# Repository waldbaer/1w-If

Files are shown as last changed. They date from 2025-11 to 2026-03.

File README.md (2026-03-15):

# 1-Wire Interface Logo

An ESP32-based 1-Wire interface supporting access with physical ethernet and MQTT protocol.

**Overview**

Overview Diagram

**Hardware**

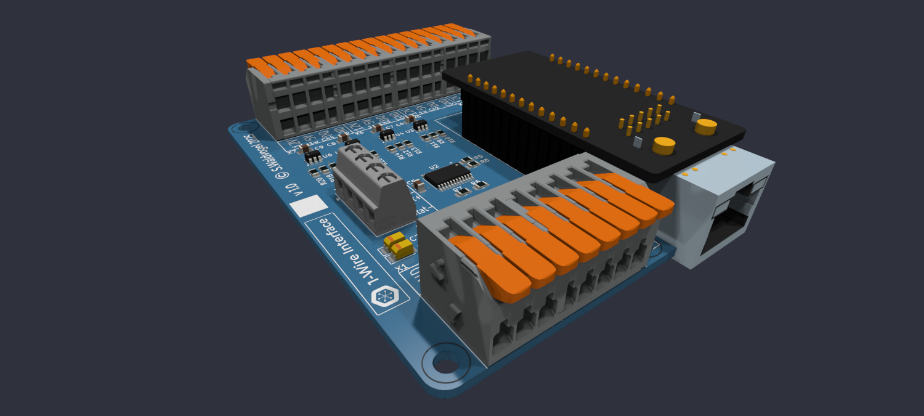
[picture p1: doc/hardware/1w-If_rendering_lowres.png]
PCB Rendering


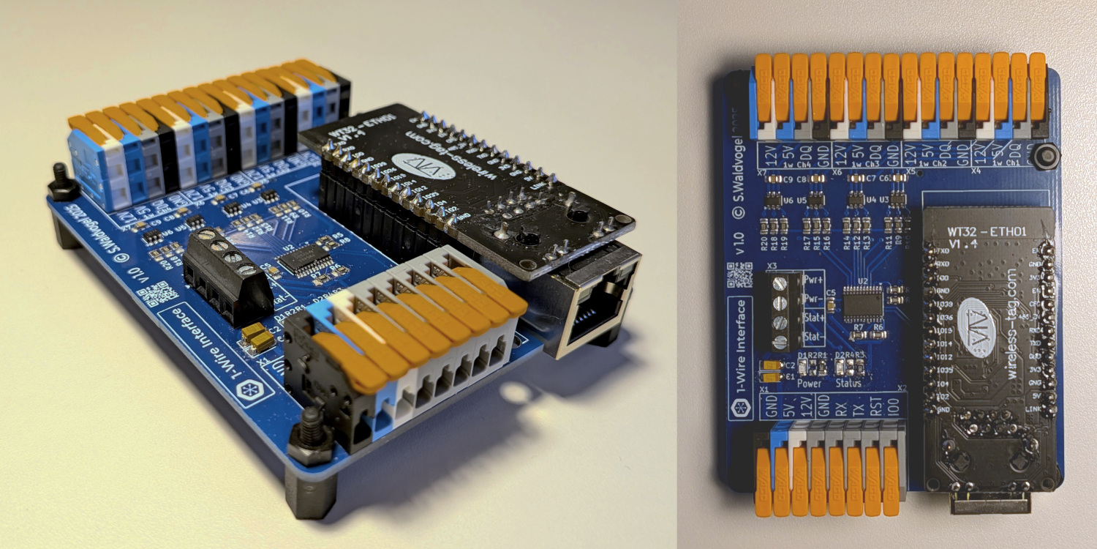
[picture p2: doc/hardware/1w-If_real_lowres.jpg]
PCB Real


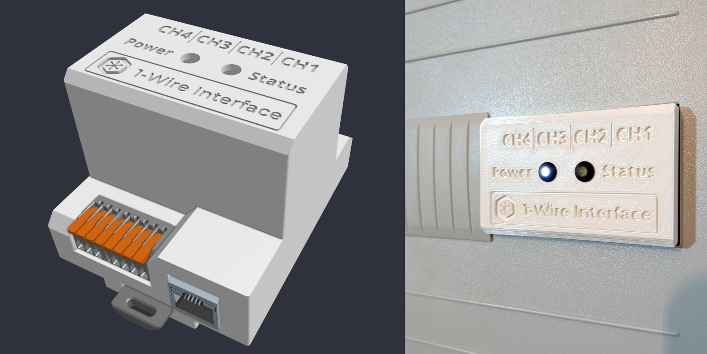
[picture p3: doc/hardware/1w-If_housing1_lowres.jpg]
Housing1


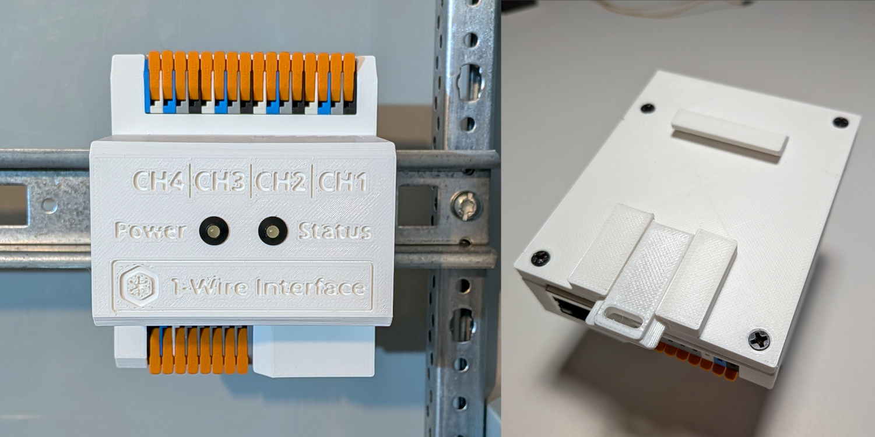
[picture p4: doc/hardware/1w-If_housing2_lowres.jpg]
Housing2


[Schematic](doc/hardware/1w-If_schematic.pdf)

## Key Features

* Access 1-wire devices via ethernet / MQTT protocol
* 4 independent 1-Wire channels with hardware bus masters
* Over-the-air (OTA) updates (web interface and espota protocol)
* Responsive web interface for configuration
  <br/>
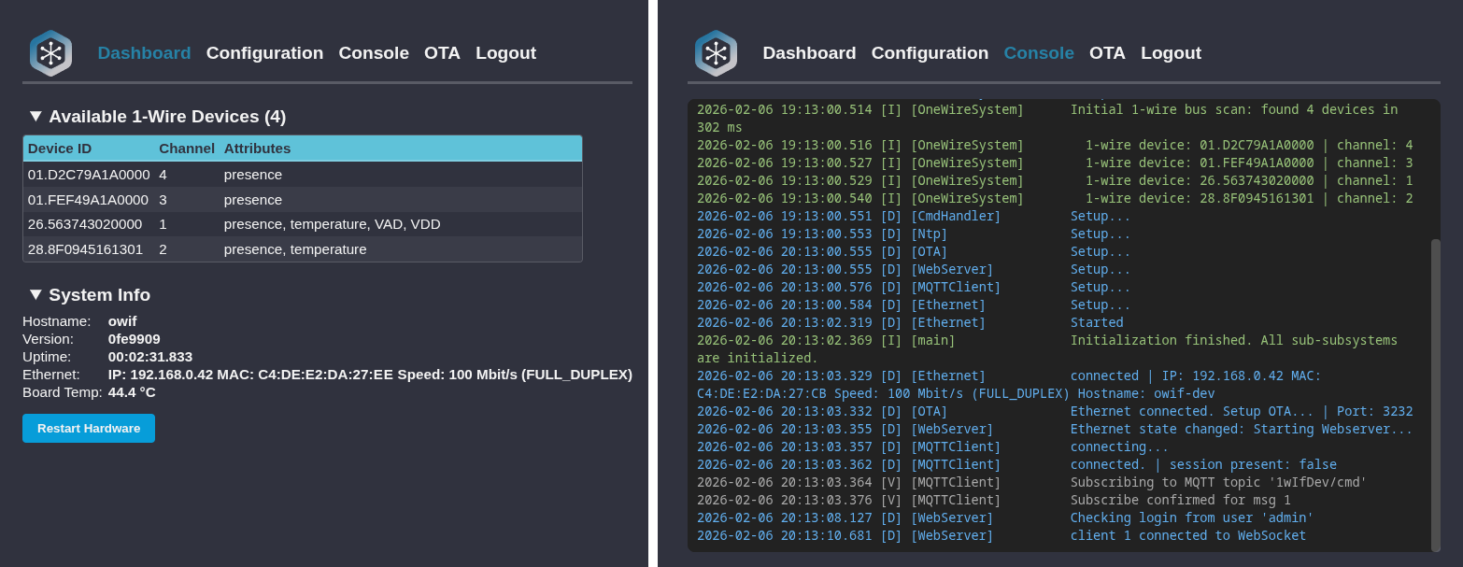
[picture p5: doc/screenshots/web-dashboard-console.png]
Screenshot Dashboard / Console
  
* NTP for clock synchronization
* 3D printed housing

## Supported 1-Wire devices

* DS2401 / DS2411 (Silicon Serial Number)
  * Unique Unique 64-Bit Serial Code

* DS18B20 (Temperature sensor)
  * Configurable resolution temperature

* DS2438  (Smart Battery Monitor)
  * Temperature, VAD, VDD

## Web-Interface

Default login:
- Username: `admin`
- Password: `1w-If`

## MQTT API
`%topic%` is a configurable prefix. Default: `1wIf`

### Commands

General MQTT topic for commands: `%topic%/cmd`

General MQTT topic for responses and status: `%topic%/stat`

Payload Format:

```
{
  "action": "<command>",
  ... action specific parameters / attributes ...
}
```

#### Command 'Restart'

Restart the entire system.
```
{
  "action": "restart",
}
```

Response:
```
{
  "action": "restart",
  "acknowledge": true,
  "time": "2026-02-03 20:20:07.955"
}
```

#### Command 'SysInfo'

Get system info.
```
{
  "action": "sysinfo",
}
```

Response:
```
{
  "action": "sysinfo",
  "state": "online",
  "version": "1.1.0",
  "uptime": "14d 12:07:12.834",
  "board_temp": 43.9,
  "ethernet": {
    "ip": "192.168.0.100",
    "mac": "89:30:5A:47:7D:0C",
    "link_speed": 100,
    "link_mode": "FULL_DUPLEX"
  },
  "time": "2026-03-15 17:02:09.720"
}
```

#### Command 'Scan'

Scan 1-wire buses for all available devices:

```
{
  "action": "scan",
}
```

Scan 1-wire buses for availability of a specific device:

```
{
  "action": "scan",
  "device_id": "01.D2C79A1A0000"
}
```

Scan 1-wire buses for availability of a specific device family:

```
{
  "action": "scan",
  "family_code": 40
}
```

The response lists all available devices and the supported attributes (for `Read` / `Subscribe` / `Unsubscribe` commands):

Example Response:
```
{
  "action": "scan",
  "devices": [
    {
      "channel": 1,
      "device_id": "01.D2C79A1A0000",
      "presence": true,
      "attributes": ["presence"]
    },
    {
      "channel": 1,
      "device_id": "28.8F0945161301",
      "presence": true,
      "attributes": ["presence", "temperature"]
    },
    {
      "channel": 2,
      "device_id": "26.563743020000",
      "presence": true,
      "attributes": ["presence", "temperature", "VAD", "VDD"]
    },
    ...
  ],
  "time": "2026-02-03 20:16:46.010"
}
```

#### Command 'Read'

Read value(s) of a single 1-wire device:

```
{
  "action": "read",
  "device_id": "28.8F0945161301",
  "attribute": "temperature"
}
```

Example Response:
```
{
  "action": "read",
  "device": {
    "channel": 1,
    "device_id": "28.8F0945161301",
    "temperature": 24.75
  },
  "time": "2025-02-03 19:10:07.955"
}
```

Read value(s) of a specific device family:

```
{
  "action": "read",
  "family_code": 40,
  "attribute": "temperature"
}
```

Example Response:
```
{
  "action": "read",
  "family_code": 40,
  "devices": [
    {
      "channel": 1,
      "device_id": "28.8F0945161301",
      "temperature": 24.75
    },
    ...
  ],
  "time": "2025-02-03 18:10:02.844"
}
```

Also the presence of a device can be accessed via the read command using the attribute `presence`.
This is similar to the scan command.

```
{
  "action": "read",
  "device_id": "28.8F0945161301",
  "attribute": "presence"
}
```

Example Response:
```
{
  "action": "read",
  "device": {
    "channel": 2,
    "device_id": "28.8F0945161301",
    "presence": true
  },
  "time": "2026-01-17 05:19:02.170"
}
```

#### Command 'Subscribe / Unsubscribe'

Subscribe to cyclic updates for 1-wire device attributes.
After successful subscription this triggers internally a `Read` command with the configured internal time.

Unit of 'interval': _milliseconds_

```
{
  "action": "subscribe",
  "device_id": "28.8F0945161301",
  "attribute": "temperature",
  "interval": 1000
}
```

Example response acknowledging the successful subscription:
```
{
  "action": "subscribe",
  "acknowledge": true,
  "device": {
    "device_id": "28.8F0945161301"
  },
  "time": "2025-08-05 13:10:22.970"
}
```

Unsubscribe from the attribute:
```
{
  "action": "unsubscribe",
  "device_id": "28.8F0945161301",
  "attribute": "temperature"
}
```

It is also possible to subscribe to the attribute `presence` to get cyclic updates about the availability of dedicated
devices:
```
{
    "action": "subscribe",
    "device_id": "01.D2C79A1A0000",
    "attribute": "presence",
    "interval": 2000
}
```

Example of the `Read` command for attribute `presence` cyclically triggered by the subscription:
```
{
  "action": "read",
  "device": {
     "channel": 3,
     "device_id": "01.D2C79A1A0000",
     "presence": false
  },
  "time": "2026-01-20 14:55:36.781"
}
```

### Last Will and Testament

The MQTT Last Will and Testament (LWT) message is published to the `%topic%/stat` topic.

The LWT contains the attribute `state` with the value `offline`.
It also includes the timestamp of when the LWT was registered with the MQTT broker.

Example:
```
{
  "state": "offline",
  "time": "2026-02-27 21:52:59.016"
}
```

During startup and registration with the MQTT broker, the same message is published with `state` set to `online`.
In this case, the timestamp contains the time of the initial MQTT subscription performed by the 1-Wire interface.

Example:
```
{
  "state": "online",
  "time": "2026-02-27 22:04:17.125"
}
```

## Development

### Firmware
```
cd firmware

# Build firmware
./build.sh

# Flash firmware + LittleFS filesystem
./flash.sh
./flash-fs.sh

# Optional: Monitor via websocket
./monitor.sh
```

Run tests
```
cd test
pdm install --dev

# Create a test_env_config.yaml in the test directory
cp example_test_env_config.yaml test_env_config.yaml
# Adapt all MQTT / device settings test_env_config.yaml
vim test_env_config.yaml

# Execute tests
pdm run tests
# Alternative: with filter
pdm run tests -k "<test name filter>"

# Lint/Format of test implementations
pdm run lint
pdm run format
```

### Hardware

- PCB designed with [KiCad](https://www.kicad.org/)
- Production files created with KiCad plugin [KiCAD JLCPCB tools](https://github.com/Bouni/kicad-jlcpcb-tools)
- Housing designed with [onshape.com](https://www.onshape.com/)

#### 3D Printing Settings

* Bottom / Top Parts:
  * Material: PLA / HPA
  * 0.4mm nozzle
  * Perimeters: 2
  * Infill:
    * General: 15%
    * Screw Domes: 100% concentric
* DIN Rail Clip:
  * Material: PETG
  * 0.4mm nozzle
  * Perimeters: 2
  * Infill:
    * General: 15%
    * Screw Domes: 100% concentric

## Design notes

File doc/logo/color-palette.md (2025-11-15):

# 1-Wire Interface - Color Palette

## Based on transparent logo
[Adobe Theme Extractor](https://color.adobe.com/de/create/image)

- <span style="color: #079DD9;">⬛</span> #079DD9
- <span style="color: #2682A6;">⬛</span> #2682A6
- <span style="color: #5FC2D9;">⬛</span> #5FC2D9
- <span style="color: #F2F2F2;">⬛</span> #F2F2F2
- <span style="color: #30323e;">⬛</span> #30323e

Extra colors:
- <span style="color: #3a3c48;">⬛</span> #3a3c48: Extra light difference to dark <span style="color: #30323e;">⬛</span> #30323e

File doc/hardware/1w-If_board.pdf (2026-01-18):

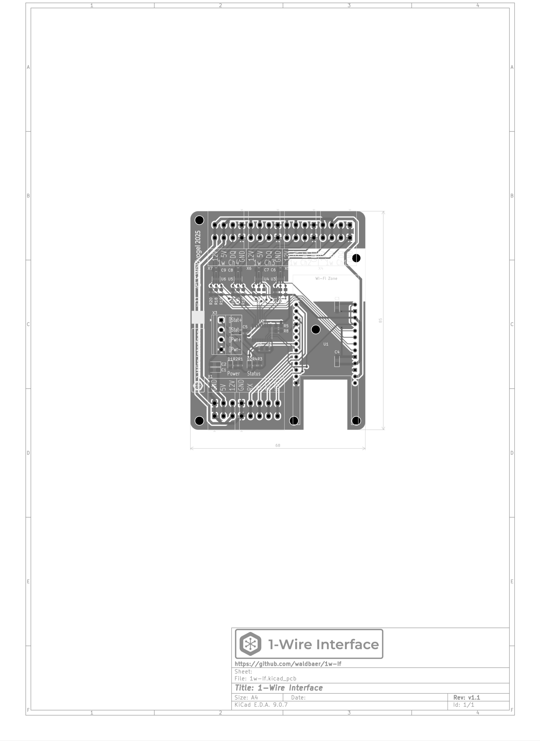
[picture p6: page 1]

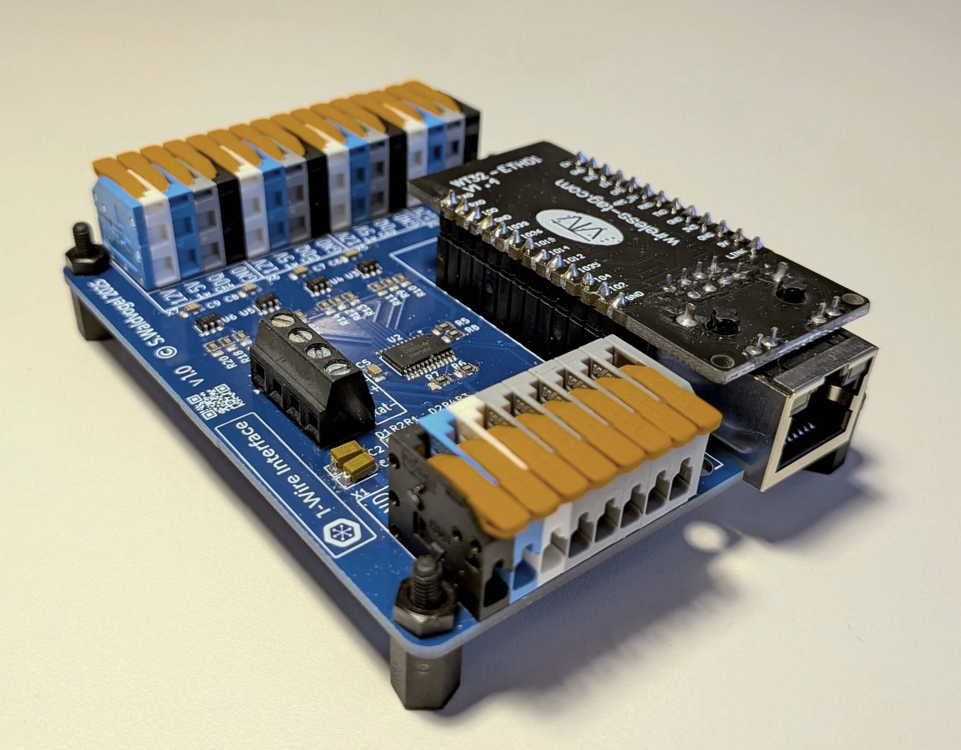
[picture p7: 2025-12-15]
doc/hardware/1w-If_real_side.jpg

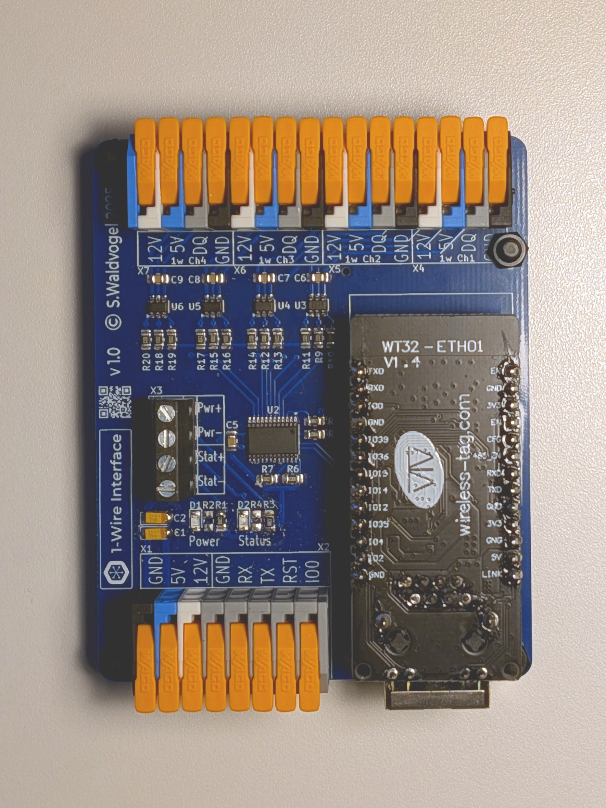
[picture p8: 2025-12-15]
doc/hardware/1w-If_real_top.jpg

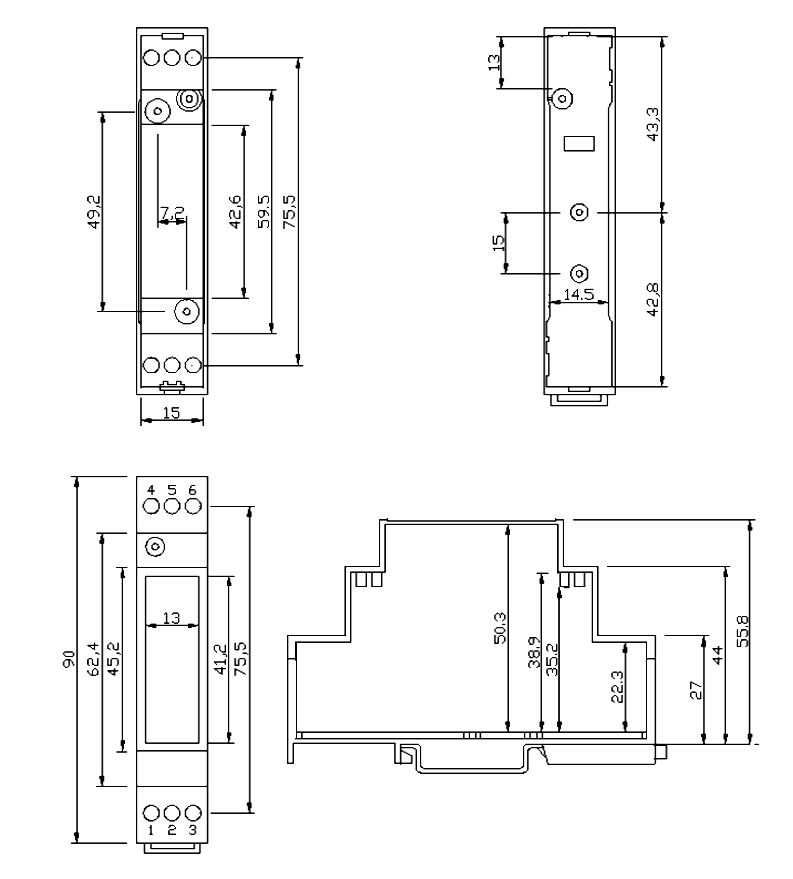
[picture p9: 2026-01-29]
doc/hardware/din-rail-dimensions.jpg

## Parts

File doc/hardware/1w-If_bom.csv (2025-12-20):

Reference | Value | Datasheet | Footprint | Qty | DNP
C1,C2,C3,C4 | 10uF | https://www.lcsc.com/product-detail/C7171.html?href=jlc-SMT%2F%3Fhref | Capacitor_Tantalum_SMD:CP_EIA-3216-18_Kemet-A_HandSolder | 4
C5,C6,C7,C8,C9 | 100nF | https://www.lcsc.com/product-detail/C49678.html?href=jlc-SMT%2F%3Fhref | Capacitor_SMD:C_0805_2012Metric_Pad1.18x1.45mm_HandSolder | 5
D1 | LED Power 5mA | https://www.lcsc.com/product-detail/C2297.html?href=jlc-SMT%2F%3Fhref | LED_SMD:LED_0805_2012Metric_Pad1.15x1.40mm_HandSolder | 1
D2 | LED Status 5mA | https://www.lcsc.com/product-detail/C2297.html?href=jlc-SMT%2F%3Fhref | LED_SMD:LED_0805_2012Metric_Pad1.15x1.40mm_HandSolder | 1
D3 | LED Power ext. 20mA | https://www.reichelt.de/de/de/shop/suche/3034W2D-EHD-A?GROUPINDEX=0&search=3034W2D-EHD-A | LED_SMD:LED_0805_2012Metric_Pad1.15x1.40mm_HandSolder | 1
D4 | LED Status ext. 20mA | https://www.reichelt.de/de/de/shop/suche/3034W2D-EHD-A?GROUPINDEX=0&search=3034W2D-EHD-A | LED_SMD:LED_0805_2012Metric_Pad1.15x1.40mm_HandSolder | 1
R1,R2,R3,R4 | 1k | https://www.lcsc.com/product-detail/C17408.html?href=jlc-SMT%2F%3Fhref | Resistor_SMD:R_0805_2012Metric_Pad1.20x1.40mm_HandSolder | 4
R5,R6,R7,R8,R9,R10,R12,R13,R15,R16,R18,R19 | 10k | https://www.lcsc.com/product-detail/C17414.html?href=jlc-SMT%2F%3Fhref | Resistor_SMD:R_0805_2012Metric_Pad1.20x1.40mm_HandSolder | 12
R11,R14,R17,R20 | 2.2k | https://www.lcsc.com/product-detail/C17520.html?href=jlc-SMT%2F%3Fhref | Resistor_SMD:R_0805_2012Metric_Pad1.20x1.40mm_HandSolder | 4
U1 | WT32-ETH01 | http://www.wireless-tag.com/wp-content/uploads/2020/08/WT32-ETH01%E8%A7%84%E6%A0%BC%E4%B9%A6V1.2EN%EF%BC%88%E8%8B%B1%E6%96%87%EF%BC%89.pdf | WT32-ETH01:WT32-ETH01_inv_mount | 1
U2 | TCA9548APWR | http://www.ti.com/lit/ds/symlink/tca9548a.pdf | Package_SO:TSSOP-24_4.4x7.8mm_P0.65mm | 1
U3,U4,U5,U6 | DS2484R | https://www.analog.com/DS2484/datasheet | Package_TO_SOT_SMD:SOT-23-6 | 4
X1 | PowerSupply | https://www.reichelt.de/de/de/shop/produkt/leiterplattenklemme_mit_hebel_1_5_mm_rm_3_5_mm_3-polig-372627 | TerminalBlock_WAGO_3D:TerminalBlock_WAGO_2601-1103_1x03_P3.50mm_Horizontal | 1
X2 | Debug Terminal | https://www.reichelt.de/de/de/shop/produkt/leiterplattenklemme_mit_hebel_1_5_mm_rm_3_5_mm_5-polig-387513 | TerminalBlock_WAGO_3D:TerminalBlock_WAGO_2601-1105_1x05_P3.50mm_Horizontal | 1
X3 | Ext LED Terminal | https://www.reichelt.de/de/de/shop/produkt/anschlussklemme_4-pol_1_5_mm_rm_3_81-72035 | TerminalBlock_MetzConnect_3D:TerminalBlock_MetzConnect_Type086_RT03404HBLC_1x04_P3.81mm_Horizontal | 1
X4 | 1-Wire Ch1 | https://www.reichelt.de/de/de/shop/produkt/leiterplattenklemme_mit_hebel_1_5_mm_rm_3_5_mm_4-polig-387512 | TerminalBlock_WAGO_3D:TerminalBlock_WAGO_2601-1104_1x04_P3.50mm_Horizontal | 1
X5 | 1-Wire Ch2 | https://www.reichelt.de/de/de/shop/produkt/leiterplattenklemme_mit_hebel_1_5_mm_rm_3_5_mm_4-polig-387512 | TerminalBlock_WAGO_3D:TerminalBlock_WAGO_2601-1104_1x04_P3.50mm_Horizontal | 1
X6 | 1-Wire Ch3 | https://www.reichelt.de/de/de/shop/produkt/leiterplattenklemme_mit_hebel_1_5_mm_rm_3_5_mm_4-polig-387512 | TerminalBlock_WAGO_3D:TerminalBlock_WAGO_2601-1104_1x04_P3.50mm_Horizontal | 1
X7 | 1-Wire Ch4 | https://www.reichelt.de/de/de/shop/produkt/leiterplattenklemme_mit_hebel_1_5_mm_rm_3_5_mm_4-polig-387512 | TerminalBlock_WAGO_3D:TerminalBlock_WAGO_2601-1104_1x04_P3.50mm_Horizontal | 1
X10,X11 | Conn_01x13_Socket | https://www.reichelt.de/de/de/shop/produkt/buchsenleiste_2_54mm_1x16_trennbar_verzinnt-283793 |  | 2

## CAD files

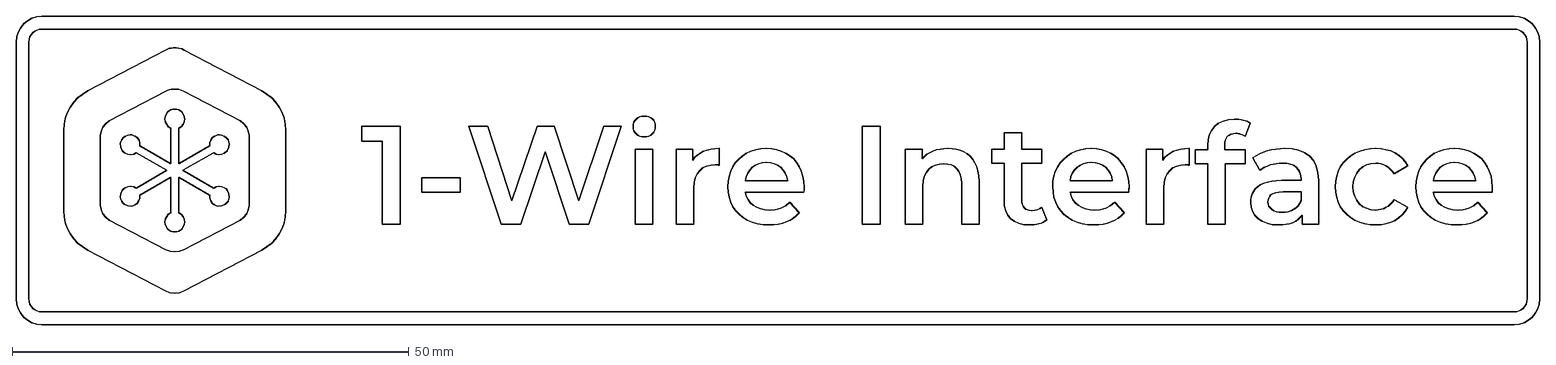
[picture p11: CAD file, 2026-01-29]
doc/logo/logo-white-transparent-framed.inkscape.dxf
192.1 x 38.9 mm

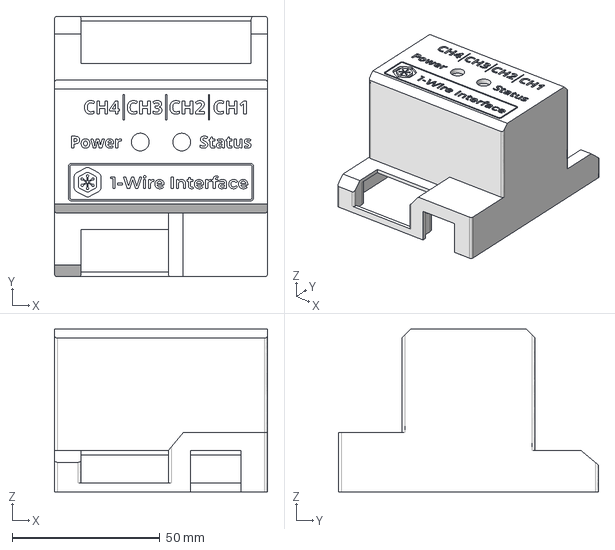
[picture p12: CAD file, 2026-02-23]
hardware/housing/1w-If Housing - Top.step
72.0 x 88.0 x 55.0 mm

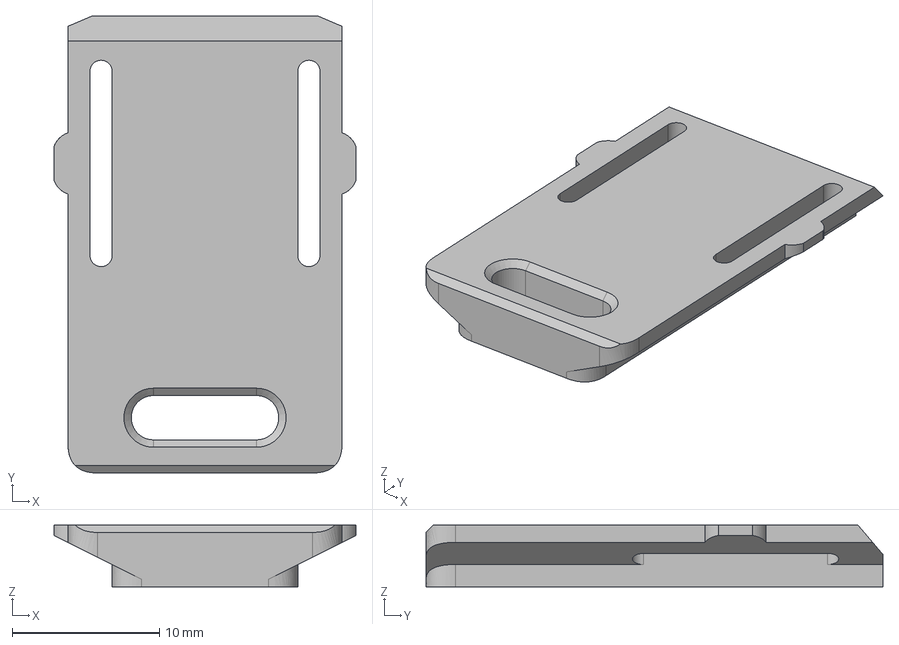
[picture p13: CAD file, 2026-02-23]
hardware/housing/1w-If Housing - DIN Rail Clip.step
20.5 x 31.0 x 4.20 mm

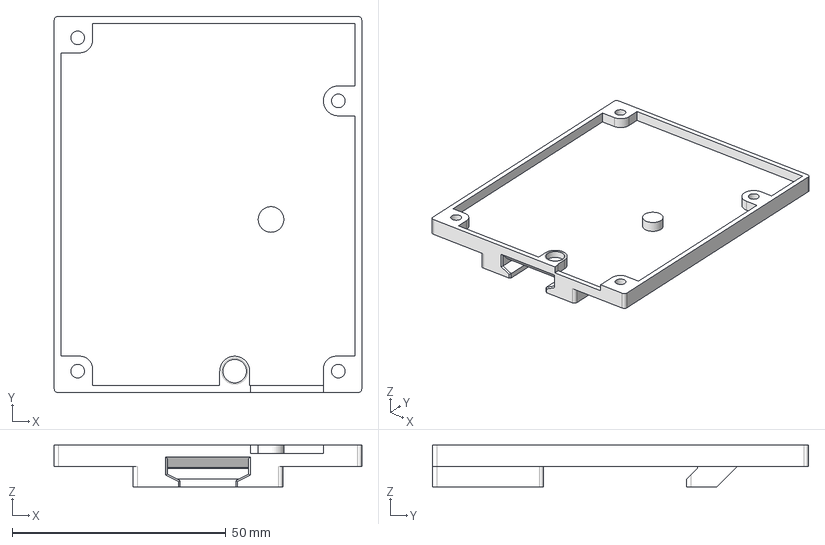
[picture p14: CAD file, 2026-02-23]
hardware/housing/1w-If Housing - Bottom.step
72.0 x 88.0 x 9.80 mm

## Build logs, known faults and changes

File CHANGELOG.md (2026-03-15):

# Changelog

All notable changes to this project will be documented in this file.

## [1.1.0] - 2026-03-15

### Features
* Support MQTT Last Will and Testament (LWT) ([#21](https://github.com/waldbaer/1w-If/pull/21))
* Support action `sysinfo` ([#24](https://github.com/waldbaer/1w-If/pull/24))

### Fixes / Improvements
* Improve housing WAGO connector cuts

### Dependencies
* Bump ESPAsyncWebServer from 3.9.5 to 3.10.1 ([#22](https://github.com/waldbaer/1w-If/pull/22), [#23](https://github.com/waldbaer/1w-If/pull/23))

## [1.0.0] - 2026-02-06

**Initial release**

### Features
* Access 1-wire devices via ethernet / MQTT protocol
* 4 independent 1-Wire channels with hardware bus masters
* Over-the-air (OTA) updates (web interface and espota protocol)
* Responsive web interface for configuration
* NTP for clock synchronization
* 3D printed housing

### Supported 1-Wire devices

* DS2401 / DS2411 (Silicon Serial Number)
  * Unique Unique 64-Bit Serial Code

* DS18B20 (Temperature sensor)
  * Configurable resolution temperature

* DS2438  (Smart Battery Monitor)
  * Temperature, VAD, VDD

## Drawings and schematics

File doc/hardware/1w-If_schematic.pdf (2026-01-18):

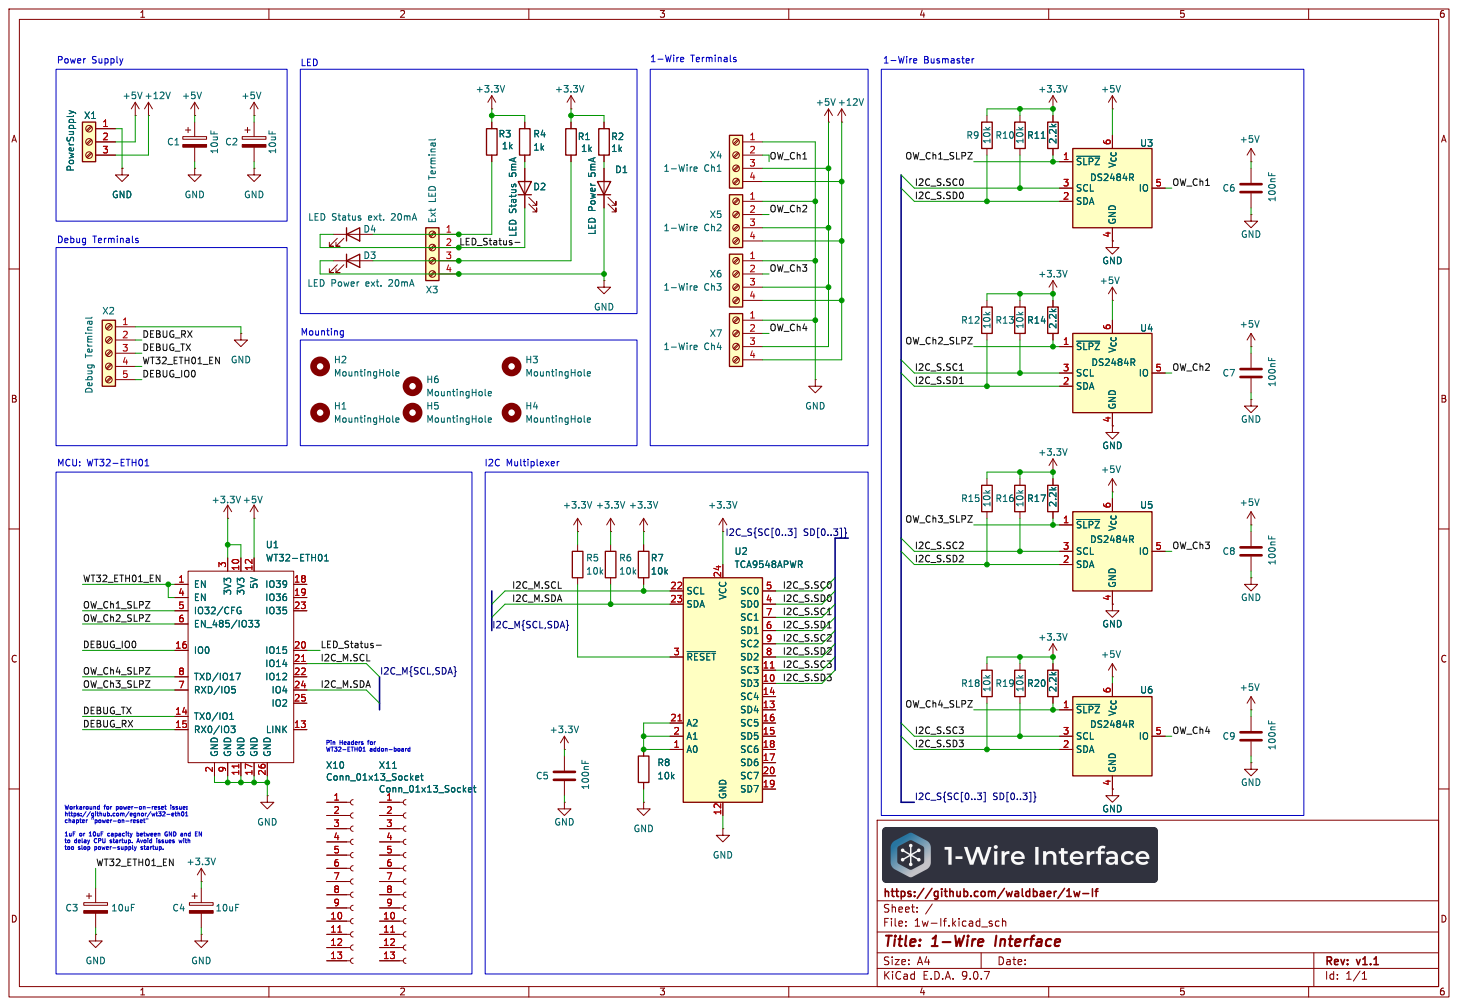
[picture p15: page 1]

File: 1w-If.kicad_sch Sheet: / https://github.com/waldbaer/1w-If

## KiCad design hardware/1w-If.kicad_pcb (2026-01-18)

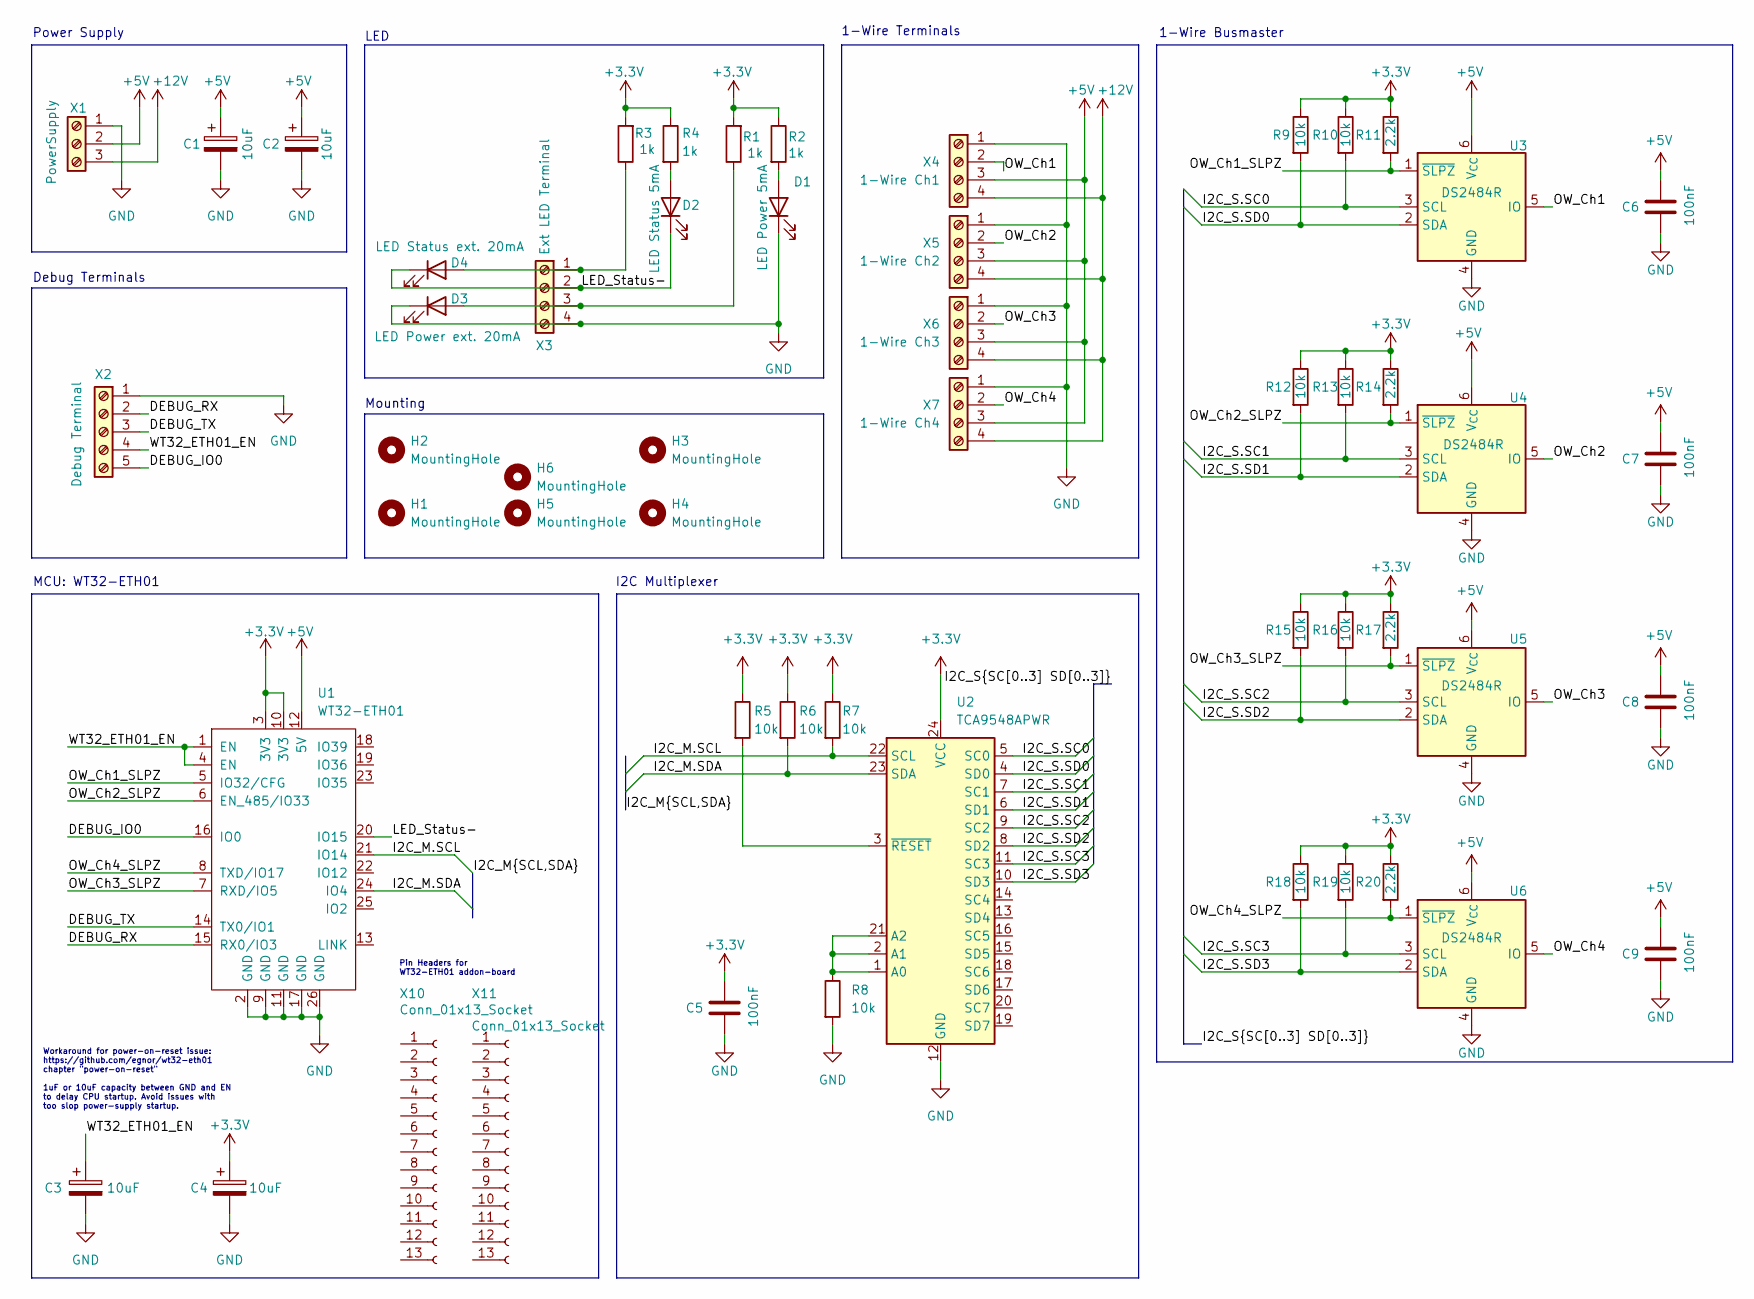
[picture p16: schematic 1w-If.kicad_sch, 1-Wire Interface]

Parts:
C1, C3, C4: 10uF; CP_EIA-3216-18_Kemet-A_HandSolder; LCSC C7171
C2: 10uF; CP_EIA-3216-18_Kemet-A_HandSolder
C5, C6, C7, C8, C9: 100nF; C_0805_2012Metric_Pad1.18x1.45mm_HandSolder; LCSC C49678
D1: LED Power 5mA; LED_0805_2012Metric_Pad1.15x1.40mm_HandSolder; LCSC C2297
D2: LED Status 5mA; LED_0805_2012Metric_Pad1.15x1.40mm_HandSolder; LCSC C34499
D3: LED Power ext. 20mA; LED_0805_2012Metric_Pad1.15x1.40mm_HandSolder; LCSC C2297
D4: LED Status ext. 20mA; LED_0805_2012Metric_Pad1.15x1.40mm_HandSolder; LCSC C2297
H1, H2, H3, H4, H5, H6: MountingHole; MountingHole_3.2mm_M3_DIN965
R1, R2, R3, R4: 1k; R_0805_2012Metric_Pad1.20x1.40mm_HandSolder; LCSC C17408
R5, R6, R7, R8, R9, R10, R12, R13, R15, R16, R18, R19: 10k; R_0805_2012Metric_Pad1.20x1.40mm_HandSolder; LCSC C17414
R11, R14, R17, R20: 2.2k; R_0805_2012Metric_Pad1.20x1.40mm_HandSolder; LCSC C17520
U1: WT32-ETH01; WT32-ETH01_inv_mount
U2: TCA9548APWR; TSSOP-24_4.4x7.8mm_P0.65mm; LCSC C130026
U3, U4, U5, U6: DS2484R; SOT-23-6; LCSC C124886
X1: PowerSupply; TerminalBlock_WAGO_2601-1103_1x03_P3.50mm_Horizontal
X2: Debug Terminal; TerminalBlock_WAGO_2601-1105_1x05_P3.50mm_Horizontal
X3: Ext LED Terminal; TerminalBlock_MetzConnect_Type086_RT03404HBLC_1x04_P3.81mm_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
X4: 1-Wire Ch1; TerminalBlock_WAGO_2601-1104_1x04_P3.50mm_Horizontal
X5: 1-Wire Ch2; TerminalBlock_WAGO_2601-1104_1x04_P3.50mm_Horizontal
X6: 1-Wire Ch3; TerminalBlock_WAGO_2601-1104_1x04_P3.50mm_Horizontal
X7: 1-Wire Ch4; TerminalBlock_WAGO_2601-1104_1x04_P3.50mm_Horizontal
X10, X11: Conn_01x13_Socket

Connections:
+3.3V: C4.1, C5.1, R1.2, R2.1, R3.2, R4.1, R5.1, R6.1, R7.1, R9.1, R10.1, R11.1, R12.1, R13.1, R14.1, R15.1, R16.1, R17.1, R18.1, R19.1, R20.1, U1.3 (3V3), U1.10 (3V3), U2.24 (VCC)
+5V: C1.1, C2.1, C6.1, C7.1, C8.1, C9.1, U1.12 (5V), U3.6 (V_{CC}), U4.6 (V_{CC}), U5.6 (V_{CC}), U6.6 (V_{CC}), X1.2, X4.3, X5.3, X6.3, X7.3
+12V: X1.3, X4.4, X5.4, X6.4, X7.4
/DEBUG_IO0: U1.16 (IO0), X2.5
/DEBUG_RX: U1.15 (RX0/IO3), X2.2
/DEBUG_TX: U1.14 (TX0/IO1), X2.3
/I2C_M.SCL: R7.2, U1.21 (IO14), U2.22 (SCL)
/I2C_M.SDA: R6.2, U1.24 (IO4), U2.23 (SDA)
/I2C_S.SC0: R10.2, U2.5 (SC0), U3.3 (SCL)
/I2C_S.SC1: R13.2, U2.7 (SC1), U4.3 (SCL)
/I2C_S.SC2: R16.2, U2.9 (SC2), U5.3 (SCL)
/I2C_S.SC3: R19.2, U2.11 (SC3), U6.3 (SCL)
/I2C_S.SD0: R9.2, U2.4 (SD0), U3.2 (SDA)
/I2C_S.SD1: R12.2, U2.6 (SD1), U4.2 (SDA)
/I2C_S.SD2: R15.2, U2.8 (SD2), U5.2 (SDA)
/I2C_S.SD3: R18.2, U2.10 (SD3), U6.2 (SDA)
/LED_Status-: D2.1 (K), D4.1 (K), U1.20 (IO15), X3.2
/OW_Ch1: U3.5 (IO), X4.2
/OW_Ch1_SLPZ: R11.2, U1.5 (IO32/CFG), U3.1 (~SLPZ)
/OW_Ch2: U4.5 (IO), X5.2
/OW_Ch2_SLPZ: R14.2, U1.6 (EN_485/IO33), U4.1 (~SLPZ)
/OW_Ch3: U5.5 (IO), X6.2
/OW_Ch3_SLPZ: R17.2, U1.7 (RXD/IO5), U5.1 (~SLPZ)
/OW_Ch4: U6.5 (IO), X7.2
/OW_Ch4_SLPZ: R20.2, U1.8 (TXD/IO17), U6.1 (~SLPZ)
/WT32_ETH01_EN: C3.1, U1.1 (EN), U1.4 (EN), X2.4
GND: C1.2, C2.2, C3.2, C4.2, C5.2, C6.2, C7.2, C8.2, C9.2, D1.1 (K), D3.1 (K), R8.2, U1.2 (GND), U1.9 (GND), U1.11 (GND), U1.17 (GND), U1.26 (GND), U2.12 (GND), U3.4 (GND), U4.4 (GND), U5.4 (GND), U6.4 (GND), X1.1, X2.1, X3.4, X4.1, X5.1, X6.1, X7.1
unnamed: D1.2 (A), R2.2
unnamed: D2.2 (A), R4.2
unnamed: R8.1, U2.1 (A0), U2.2 (A1), U2.21 (A2)
unnamed: R5.2, U2.3 (~RESET)
unnamed: D4.2 (A), R3.1, X3.1
unnamed: D3.2 (A), R1.1, X3.3

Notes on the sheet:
1-Wire Busmaster
MCU: WT32-ETH01
Pin Headers for WT32-ETH01 addon-board
1-Wire Terminals
I2C Multiplexer
LED
Debug Terminals
Mounting
Workaround for power-on-reset issue: https://github.com/egnor/wt32-eth01 chapter "power-on-reset" 1uF or 10uF capacity between GND and EN to delay CPU startup. Avoid issues with too slop power-supply startup.
Power Supply

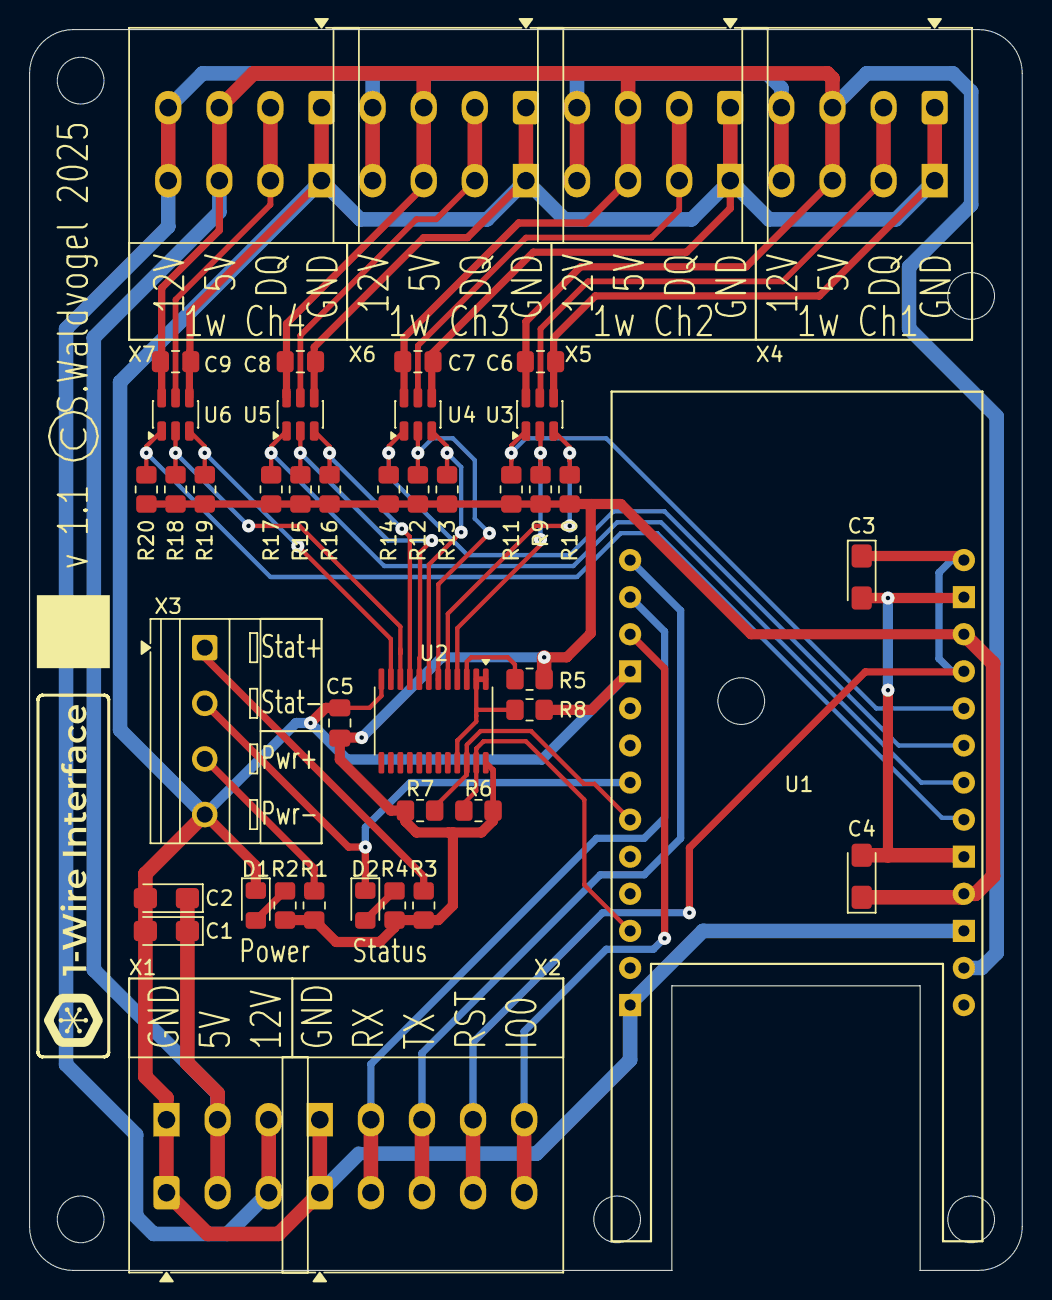
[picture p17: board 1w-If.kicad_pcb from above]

Board: 2 copper layers, 68.0 x 85.0 mm, 50 parts (0 on the bottom side), 33 nets.

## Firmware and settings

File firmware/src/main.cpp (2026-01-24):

/*! --------------------------------------------------------------------------------------------------------------------
 * 1w-If (1-Wire Interface)
 * An ESP32-based 1-Wire interface supporting access with physical ethernet and MQTT protocol.
 *
 * Copyright (c) 2025 Sebastian Waldvogel
 * ------------------------------------------------------------------------------------------------------------------ */

#include <Arduino.h>

#include "cmd/command_handler.h"
#include "config/persistency.h"
#include "ethernet/ethernet.h"
#include "logging/logger.h"
#include "logging/multi_logger.h"
#include "logging/status_led.h"
#include "logging/web_socket_logger.h"
#include "mqtt/mqtt_client.h"
#include "mqtt/mqtt_message_handler.h"
#include "one_wire/ds18b20.h"
#include "one_wire/one_wire_subsystem.h"
#include "ota/ota.h"
#include "time/ntp_client.h"
#include "util/abort_handler.h"
#include "version_info.h"
#include "web_server/web_server.h"

namespace owif {

static constexpr std::uint32_t kSerialBaudRate{SERIAL_BAUD};  // SERIAL_BAUD defined by build process
static constexpr std::uint8_t kStatusLedPin{15};              // GPIO15. Active Low.

std::size_t publish_counter{0};

auto owif_setup() -> void {
  // Setup Status LED & flash it initially
  bool setup_result{logging::status_led_g.Begin(kStatusLedPin)};

  logging::status_led_g.Flash(2);

  // Setup Logging
  config::LoggingConfig const logging_config{config::persistency_g.LoadLoggingConfig()};
  if (logging_config.GetSerialLogEnabled()) {
    Serial.begin(kSerialBaudRate);
    setup_result &= logging::multi_logger_g.RegisterLogSink(Serial);
  }
  setup_result &= logging::logger_g.Begin(logging::multi_logger_g, logging_config.GetLogLevel());

  if (logging_config.GetWebLogEnabled()) {
    setup_result &= logging::web_socket_logger_g.Begin(web_server::web_server_g.GetWebSocket());
    setup_result &= logging::multi_logger_g.RegisterLogSink(logging::web_socket_logger_g);
  }

  // Terminate Handler
  SetupTerminateHandler();

  // Print Version and Configuration
  logging::logger_g.Info(F("[main] +-- 1-Wire Interface -----------------------------"));
  logging::logger_g.Info(F("[main] | Version: %s"), kOwIfVersion);
  logging::logger_g.Info(F("[main] +-------------------------------------------------"));

  config::persistency_g.PrettyPrint(logging::logger_g);

  setup_result &= one_wire::one_wire_system_g.Begin(config::persistency_g.LoadOneWireConfig());
  setup_result &= cmd::command_handler_g.Begin(&one_wire::one_wire_system_g);

  // Setup OTA / WebServer / MqttClient before Ethernet to allow registration of ConnectionStateChangeHandlers
  setup_result &= time::ntp_client_g.Begin(config::persistency_g.LoadNtpConfig());
  setup_result &= ota::ota_system_g.Begin();
  setup_result &= web_server::web_server_g.Begin(one_wire::one_wire_system_g);
  setup_result &= mqtt::mqtt_client_g.Begin();
  setup_result &= mqtt::mqtt_msg_handler_g.Begin(&mqtt::mqtt_client_g, &cmd::command_handler_g);

  setup_result &= ethernet::ethernet_g.Begin();

  if (setup_result) {
    logging::logger_g.Info(F("[main] Initialization finished. All sub-subsystems are initialized."));

    // Flash status LED 2 times and finally turn it on.
    logging::status_led_g.Flash(2);
    logging::status_led_g.On();
  } else {
    logging::logger_g.Abort(F("[main] Initialization failed. Please check previous outputs."));

    // Flash status LED 10 times and finally turn it off.
    logging::status_led_g.Flash(10);
    logging::status_led_g.Off();
  }
}

auto owif_loop() -> void {
  time::ntp_client_g.Loop();
  ota::ota_system_g.Loop();
  one_wire::one_wire_system_g.Loop();
  web_server::web_server_g.Loop();
  mqtt::mqtt_client_g.Loop();
  mqtt::mqtt_msg_handler_g.Loop();
  cmd::command_handler_g.Loop();
}

}  // namespace owif

// ---- Arduino Main Entrypoint Functions ------------------------------------------------------------------------------
auto setup() -> void { owif::owif_setup(); }
auto loop() -> void { owif::owif_loop(); }
// ---------------------------------------------------------------------------------------------------------------------

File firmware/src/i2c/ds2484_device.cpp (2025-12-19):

#include "i2c/ds2484_device.h"

#include <Arduino.h>

#include "util/language.h"

namespace owif {
namespace i2c {

// ---- Public APIs ----------------------------------------------------------------------------------------------------
Ds2484Device::Ds2484Device(I2CBus& i2c_bus,
                           // PullUp Config
                           bool active_pullup, bool strong_pullup,
                           // Timing Config
                           std::uint8_t tRSTL, std::uint8_t tMSP, std::uint8_t tW0L, std::uint8_t tREC0,
                           std::uint8_t RWPU)
    : I2CDevice{i2c_bus, kI2CAddress},
      active_pullup_{active_pullup},
      strong_pullup_{strong_pullup},
      tRSTL_{tRSTL},
      tMSP_{tMSP},
      tW0L_{tW0L},
      tREC0_{tREC0},
      RWPU_{RWPU} {}

auto Ds2484Device::Begin() -> bool {
  bool result{true};

  result &= ResetDevice();
  result &= ResetOneWire();

  return result;
}

auto Ds2484Device::Read8(std::uint8_t& value) -> bool {
  std::uint8_t read8_cmd{ToUnderlying(Command::OneWireReadByte)};

  bool result{write(&read8_cmd, 1) == i2c::ERROR_OK};

  if (result) {
    result &= WaitForCompletion();
  }

  if (result) {
    // Set the ReadPointer to the 'ReadDataRegister'
    std::uint8_t set_read_reg_cmd[2]{ToUnderlying(Command::SetReadPointer),
                                     // param: Sets the read pointer to the specified register
                                     ToUnderlying(ReadPointerCode::ReadDataRegister)};
    result &= write(set_read_reg_cmd, 2) == i2c::ERROR_OK;
  }

  if (result) {
    // Finally read the value of the 'ReadDataRegister'
    result &= read(&value, 1) == i2c::ERROR_OK;
  }

  if (!result) {
    logger_.Error(F("[DS2484] Failed to read a byte"));
  }

  return result;
}

auto Ds2484Device::Read64(std::uint64_t& value) -> bool {
  bool result{true};

  value = 0;
  for (std::uint8_t i = 0; i < 8; i++) {
    std::uint8_t read_byte;
    result &= Read8(read_byte);
    value |= (read_byte << (i * 8));
  }
  return result;
}

auto Ds2484Device::Write8(std::uint8_t value) -> bool {
  std::uint8_t const cmd[2]{ToUnderlying(Command::OneWireWriteByte), value};
  bool result{write(cmd, 2) == ErrorCode::ERROR_OK};
  result &= WaitForCompletion();

  return result;
};

auto Ds2484Device::Write64(std::uint64_t value) -> bool {
  bool result{true};
  for (std::uint8_t i{0}; i < 8; i++) {
    result &= Write8((value >> (i * 8)) & 0xFF);
  }
  return result;
}

auto Ds2484Device::ResetOneWire() -> bool {
  std::uint8_t reset_ow_cmd{ToUnderlying(Command::OneWireReset)};
  if (write(&reset_ow_cmd, 1) != i2c::ERROR_OK) {
    logger_.Error(F("[DS2484] Failed to write OneWireReset command"));
    return false;
  }
  if (!WaitForCompletion()) {
    logger_.Error(F("[DS2484] ResetOneWire: can't complete"));
    return false;
  }
  return true;
}

auto Ds2484Device::OneWireTriple(bool* branch, bool* id_bit, bool* cmp_id_bit) -> bool {
  std::uint8_t status;
  if (!ReadStatus(&status)) {
    logger_.Error(F("[DS2484] OneWireTriple: read status error"));
    return false;
  }

  std::uint8_t cmd_buffer[2]{
      ToUnderlying(Command::OneWireTriplet),
      // parameter: DirectionByte: DS2484 generates a write-one time slot if V = 1 and a write-zero time slot if V = 0
      (*branch ? ToUnderlying(DirectionByte::WriteOneTimeSlot) : ToUnderlying(DirectionByte::WriteZeroTimeSlot))};
  if (write(cmd_buffer, 2) != i2c::ERROR_OK) {
    logger_.Error(F("[DS2484] Failed to write OneWireTriple command"));
    return false;
  }

  if (!ReadStatus(&status)) {
    logger_.Error(F("[DS2484] OneWireTriple: read status error"));
    return false;
  }

  *id_bit = static_cast<bool>(status & ToUnderlying(StatusReg::SBR));
  *cmp_id_bit = static_cast<bool>(status & ToUnderlying(StatusReg::TSB));
  *branch = static_cast<bool>(status & ToUnderlying(StatusReg::DIR));

  return true;
}

// ---- Private APIs ---------------------------------------------------------------------------------------------------

auto Ds2484Device::ResetDevice() -> bool {
  bool result{true};

  std::uint8_t device_reset_cmd{ToUnderlying(Command::DeviceReset)};
  if (write(&device_reset_cmd, 1) != i2c::ERROR_OK) {
    logger_.Error(F("[DS2484] Failed to write ResetDevice command"));
    return false;
  }
  if (!WaitForCompletion()) {
    logger_.Error(F("[DS2484] ResetDevice: can't complete"));
    return false;
  }
  std::uint8_t config{static_cast<std::uint8_t>((active_pullup_ ? ToUnderlying(DeviceConfigReg::APU) : 0) |
                                                (strong_pullup_ ? ToUnderlying(DeviceConfigReg::SPU) : 0))};
  std::uint8_t write_config[2]{
      ToUnderlying(Command::WriteDeviceConfig),
      static_cast<std::uint8_t>(
          config |
          // When writing to the Device Configuration register, the new data is accepted only if the
          // upper nibble (bits 7 to 4) is the one’s complement of the lower nibble (bits 3 to 0).
          (~config << 4))};
  if (write(write_config, 2) != i2c::ERROR_OK) {
    logger_.Error(F("[DS2484] Failed to write config"));
    return false;
  }

  // After WriteDeviceConfig the read pointer is directly set to the config register.
  // Read it and compare with written config. Attention: When read, the upper nibble is always 0h.
  std::uint8_t response;
  if (read(&response, 1) != i2c::ERROR_OK) {
    logger_.Error(F("[DS2484] Failed to read config response"));
    return false;
  }

  if (response != (write_config[1] & 0x0F)) {
    logger_.Error(F("[DS2484] Config response does not match expected config"));
    return false;
  }

  // Check 1-wire port configuration registers
  std::uint8_t ow_port_config[8]{0};
  ReadOneWirePortConfig(ow_port_config);
  for (std::uint8_t byte : ow_port_config) {
    if (byte != kDefaultOneWirePortConfigValueCode) {
      logger_.Error(F("[DS2484] Unexpected 1-wire port configuration register value detected: %X"), byte);
    }
  }

  if (tRSTL_ != kDefaultOneWirePortConfigValueCode) {
    result &= WriteOneWirePortConfig(ControlByteParamSelection::tRSTL, tRSTL_);
  }
  if (tMSP_ != kDefaultOneWirePortConfigValueCode) {
    result &= WriteOneWirePortConfig(ControlByteParamSelection::tMSP, tMSP_);
  }
  if (tW0L_ != kDefaultOneWirePortConfigValueCode) {
    result &= WriteOneWirePortConfig(ControlByteParamSelection::tW0L, tW0L_);
  }
  if (tREC0_ != kDefaultOneWirePortConfigValueCode) {
    result &= WriteOneWirePortConfig(ControlByteParamSelection::tREC0, tREC0_);
  }
  if (RWPU_ != kDefaultOneWirePortConfigValueCode) {
    result &= WriteOneWirePortConfig(ControlByteParamSelection::RWPU, RWPU_);
  }

  // Check 1-wire port config after re-configuration
  ReadOneWirePortConfig(ow_port_config);

  result &= ow_port_config[0] == tRSTL_;
  result &= ow_port_config[2] == tMSP_;
  result &= ow_port_config[4] == tW0L_;
  result &= ow_port_config[6] == tREC0_;
  result &= ow_port_config[7] == RWPU_;
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

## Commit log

2025-09-28 1w-If: Initial version
    [partitions.csv]
2025-10-03 Improve OneWireAddress, Timer and string logging
2025-10-05 Fix single device search
2025-10-05 Support attribute 'presence' for all device families
2025-10-27 Fix: Missing device for action scan all
2025-11-02 Show 1-wire devices on dashboard (#4)
2025-11-06 Show actual devices instead of test devicelist
2025-11-06 show actual devices instead of test data
2025-11-15 [WebServer] fix javascript error in console
    [main.cpp]
2025-11-16 [Logging] Fix broken logs during startup
    [main.cpp]
2025-11-16 Add one-wire channel to MQTT protocol and web UI overview (#7)
2025-11-26 More logo vectorization
    * Vectorize logo font
    * Add logo font 'Montserrat' to repo
    * Add logo variant 'logo-white-transparent-framed'
2025-12-02 Hardware PCB for 1w-If (v1.0) (#8)
    [1w-If.kicad_pcb, 1w-If.kicad_sch]
2025-12-06 Add more PCB parts
2025-12-06 Improve 3D model of WT32-ETH01
    [1w-If.kicad_pcb]
2025-12-14 PCB v1.1 (#9)
    - Add missing polarity of tantal capacities C1-C4.
    - Too bright LEDs: R1-R4 changed to 1kOhm
    - Swapped ext. LED connector silk layer description
    [1w-If.kicad_pcb, 1w-If.kicad_sch]
2025-12-14 Support 4 independent 1-wire channels (#10)
    - Support 4 1-wire channels and status LED
2025-12-15 Add PCB pictures
2025-12-16 Introduce LedStatus abstraction
2025-12-19 Configurable 1-Wire channel activation (#11)
2025-12-20 Added pin connectors for WT32_ETH01 Reworked BOM / datasheets
    [1w-If.kicad_pcb, 1w-If.kicad_sch, 1w-If_bom.csv]
2025-12-20 Fix schematic link
2025-12-30 Sorted devices list and devices web UI improvements
2026-01-11 Bump esp32async/ESPAsyncWebServer from 3.8.1 -> 3.9.4 (#15)
2026-01-18 Rework logo: thicker star
    [1w-If.kicad_pcb, 1w-If.kicad_sch, logo-white-transparent-framed.inkscape.dxf]
2026-01-29 DIN Rail Housing (3D Print) (#18)
    [1w-If Housing - Bottom.step, 1w-If Housing - DIN Rail Clip.step, 1w-If Housing - Top.step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]
2026-02-01 Show CPU temperature on dashboard
2026-02-03 Add current timestamp to JSON responses (#19)
2026-02-03 Move firmware into subfolder (#20)
    [partitions.csv]
2026-02-06 [Housing] Add ventilation cuts
    [1w-If Housing - Bottom.step, 1w-If Housing - DIN Rail Clip.step, 1w-If Housing - Top.step]
2026-02-06 Flash status LED while command processing
2026-02-23 [Housing] Improve north/south WAGO cuts
    [1w-If Housing - Bottom.step, 1w-If Housing - DIN Rail Clip.step, 1w-If Housing - Top.step]
2026-02-27 [Housing] Update pictures
2026-02-27 [Housing] Update rendering
2026-06-08 Bump bblanchon/ArduinoJson from 7.4.2 to 7.4.3 (#26)
2026-06-08 Bump esp32async/ESPAsyncWebServer from 3.10.1 to 3.11.1 (#28)
